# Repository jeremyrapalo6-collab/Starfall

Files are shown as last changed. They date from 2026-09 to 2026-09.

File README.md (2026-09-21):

# Starfall

Starfall is my first hardware project. I wanted to make a macropad because it seemed cool, and I chose to use my favorite colors, black and purple, along with my group name, **LTC**. This was a cool but long project, and I learned a lot while making it.

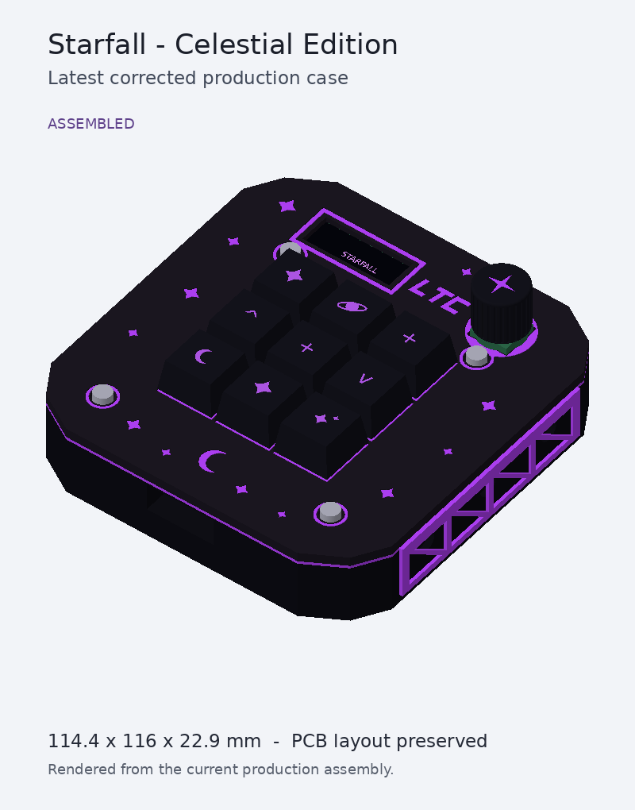
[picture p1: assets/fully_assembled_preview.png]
Starfall Celestial case


## What it is

Starfall is a 9-key macropad with a rotary encoder and a small OLED display. I designed it around a Seeed Studio XIAO RP2040 and made a custom PCB and case for it.

The macropad has three modes:

- **Everyday** - shortcuts for normal computer use
- **Gaming** - keys for games
- **Coding** - shortcuts for VS Code and Python

The bottom-right key changes between the three modes, and the OLED shows which mode is active.

## Design

The Celestial case pairs a black shell with purple side trusses, stars, a crescent and a bold slanted LTC logo. It has a stepped OLED surround and a recessed USB-C opening. Keycap symbols are illustrative; the preview includes the printable Starfall star knob.

## Hardware

- Seeed Studio XIAO RP2040
- 9 MX-compatible switches
- 9 1N4148 diodes
- 0.91-inch SSD1306 I2C OLED
- EC11 rotary encoder
- Custom 2-layer PCB
- Custom 3D-printed case
- 9 keycaps
- M3 screws and heat-set inserts

## Firmware

The firmware uses **KMK / CircuitPython**.

The three layers are:

### Everyday
Copy, paste, cut, undo, redo, select all, screenshot, media play/pause, and mode change.

### Gaming
A set of gaming keys plus the mode-change key.

### Coding
VS Code shortcuts such as run, debug, format, comment, terminal, split editor, command palette, quick open, and mode change.

## PCB

### Schematic

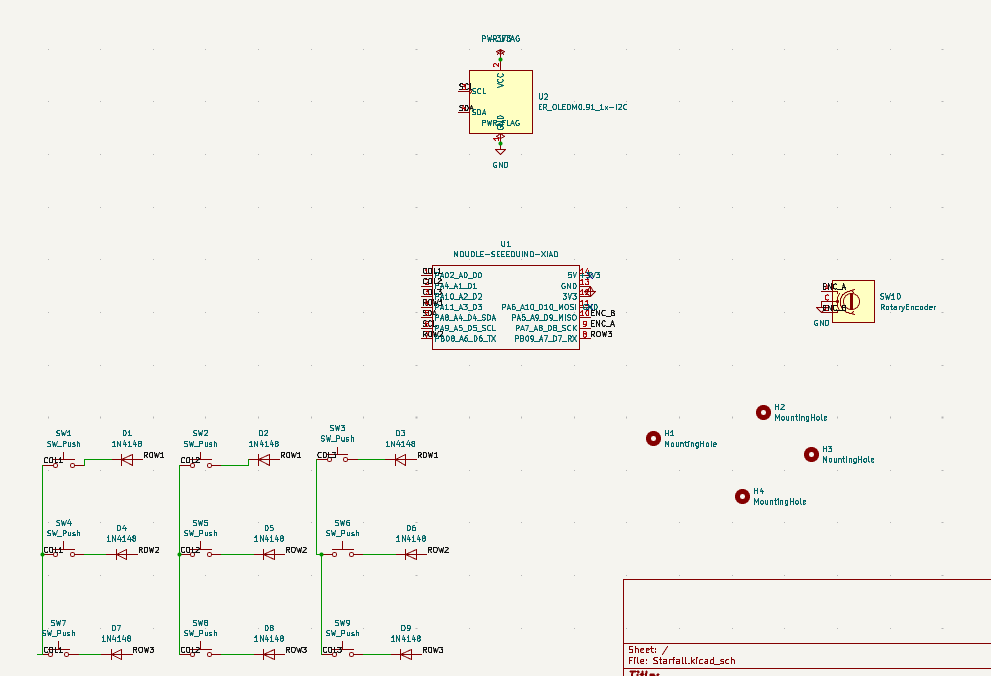
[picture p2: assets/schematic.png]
Starfall schematic


### PCB layout

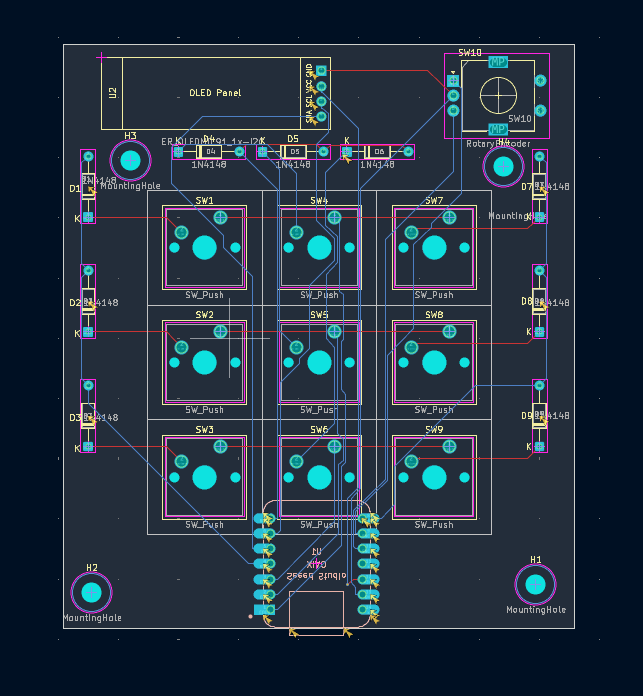
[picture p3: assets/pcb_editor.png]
Starfall PCB layout


### Front 3D view

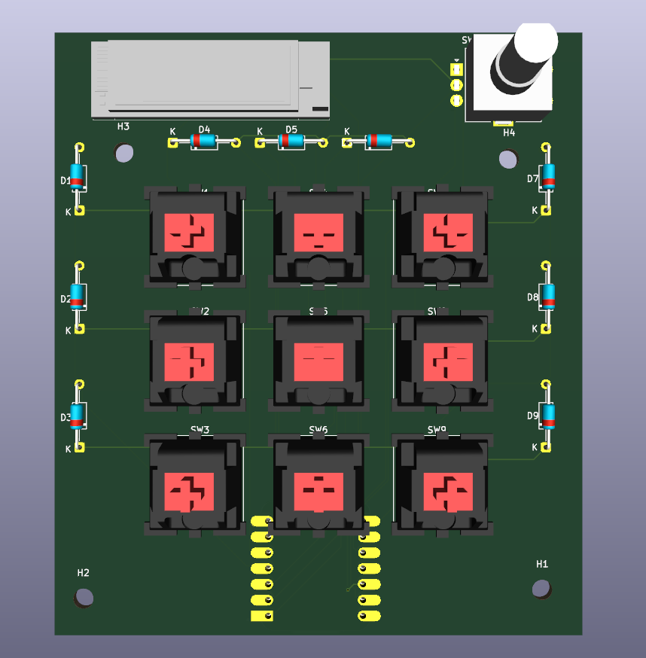
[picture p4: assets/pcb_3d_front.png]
Starfall PCB front


### Back 3D view

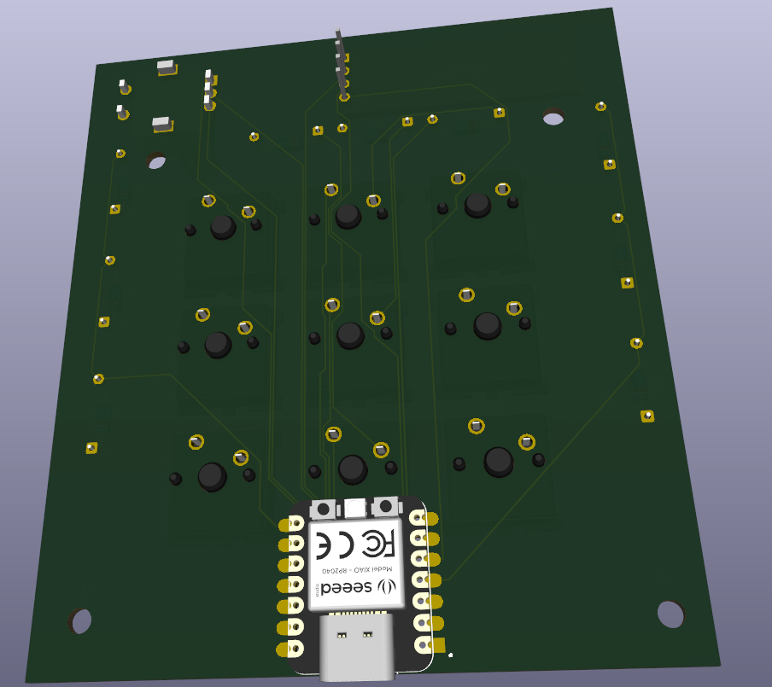
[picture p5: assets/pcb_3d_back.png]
Starfall PCB back


### Gerber check

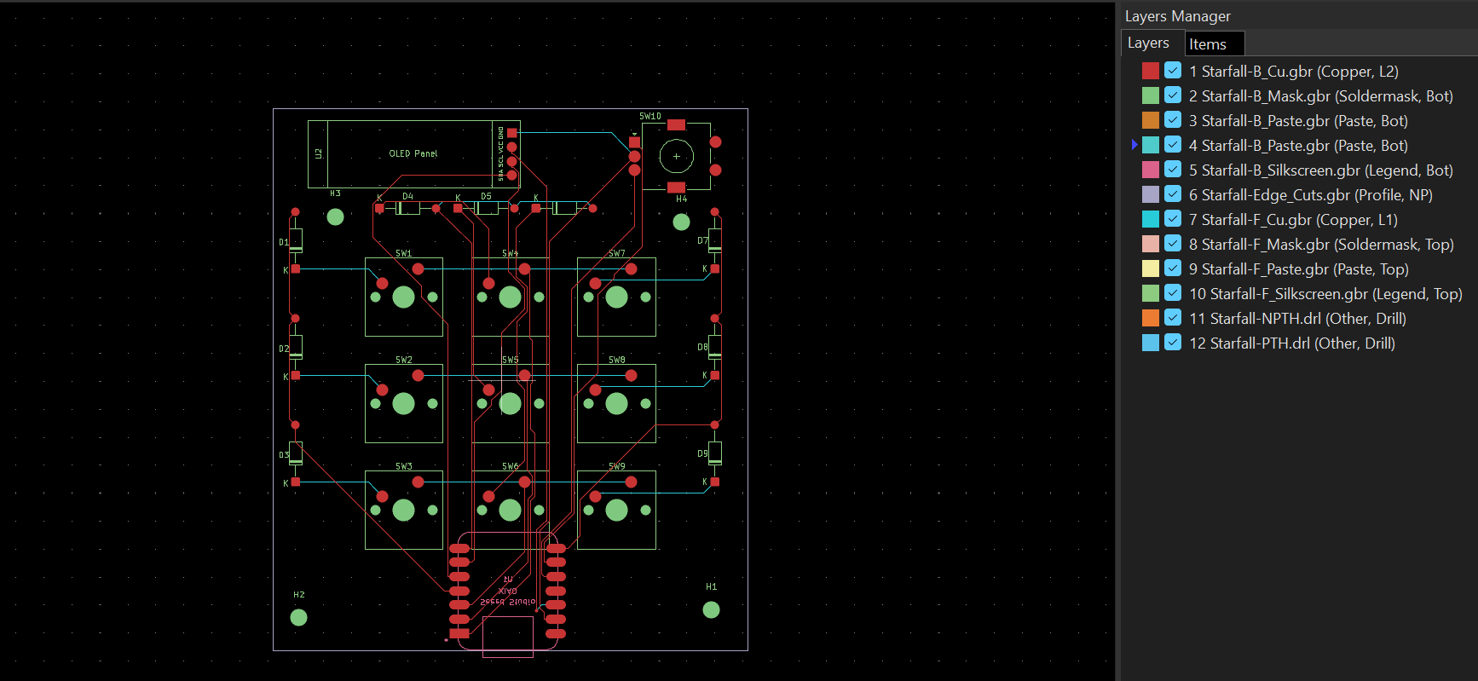
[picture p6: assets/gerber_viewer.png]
Starfall Gerber Viewer


## Case

The current case is **Starfall Celestial** (114.4 x 116 x 22.9 mm including side trusses).

- Black: `production/Top.STEP` and `production/Bottom.STEP`.
- Purple: `production/Middle_Purple.STEP` and `production/Purple_Inlays_Print_Layout.STEP` (one set of accents).
- Matching STL files are provided. `Purple_Inlays.STEP` is the same accents in assembled positions: do not print both accent files.
- [Fully assembled STEP](CAD/Starfall_Fully_Assembled.STEP) and [colored GLB](CAD/Starfall_Fully_Assembled_Colored.glb).
- [Design changes and physical fit checks](DESIGN_NOTES.md) and [assembly instructions](CAD/MECHANICAL_NOTES.md).

The L has been shifted 0.35 mm right. The taller bottom retains M3x16 screws with recessed insert seats. The PCB layout is unchanged. Print the switch/insert coupons and check your actual cable before a full case: CAD checks do not guarantee physical fit. All files in production are current. The case PNGs and older assembly filenames are synchronized to the latest Celestial case; PCB screenshots describe the unchanged PCB.

Automated CAD results: [mechanical](production/MECHANICAL_VALIDATION.json), [exports](production/EXPORT_VALIDATION.json), [structural intersections](production/STRUCTURAL_COLLISIONS.json).

### Current case views

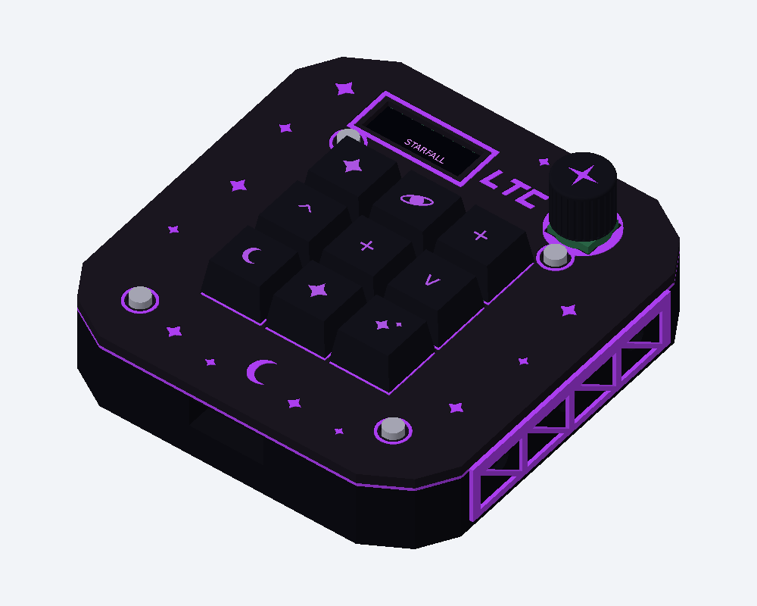
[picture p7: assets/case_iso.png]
Current assembled angled view


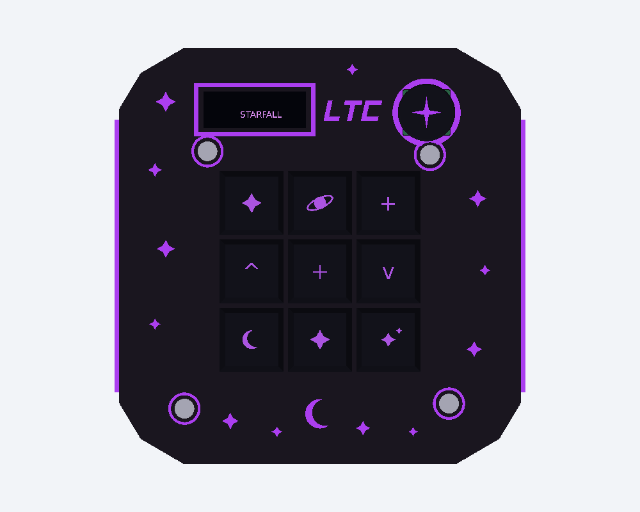
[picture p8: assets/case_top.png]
Current top view


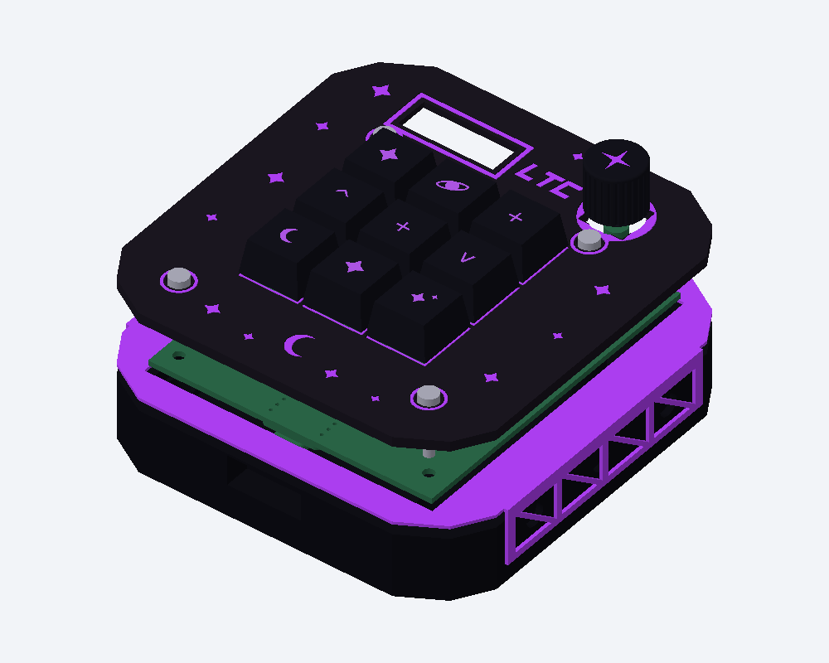
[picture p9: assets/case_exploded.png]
Current exploded assembly


These views are rendered from the current assembly. Keycaps and legends are illustrative accessories; the knob matches the printable files. See [asset descriptions](assets/SCREENSHOTS.md).

[Download the complete printer ZIP (case + knob + samples)](production/Starfall-Complete-Printer-Pack.zip).

### Printable Starfall encoder knob

[Download the knob print pack](production/knob/Starfall-Knob-Print-Pack.zip) or browse [individual STL/STEP files and instructions](production/knob/README.md).

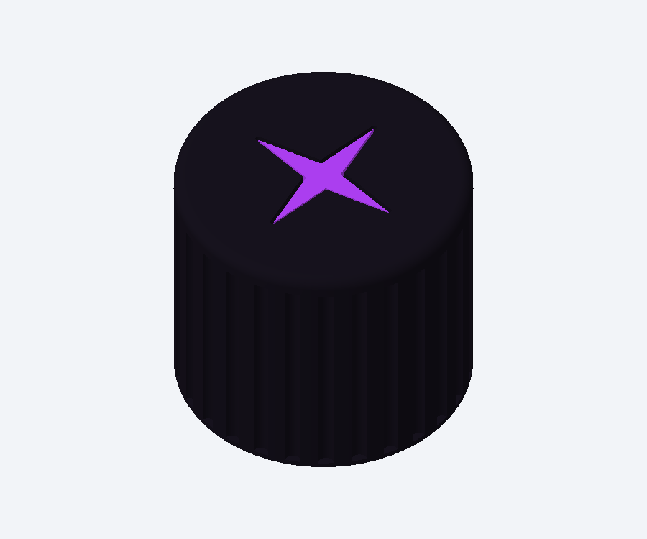
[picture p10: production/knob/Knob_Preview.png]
Black fluted knob with purple star


Print `Knob_Black.stl` in black and `Knob_Star_Purple.stl` in purple. Test `Dshaft_sample_6p2mm.stl` on the actual encoder first. The 6.1 and 6.3 mm samples provide fit alternatives; change the knob bore if needed before printing. Modeled clearances pass, but physical shaft fit and push travel require testing. Full-case previews and assembled STEP/GLB files now include this printable star knob.

## Bill of Materials

| Item | Qty | Part / Specification | Notes |
| --- | ---: | --- | --- |
| Microcontroller | 1 | Seeed Studio XIAO RP2040 | Hackpad MCU |
| Mechanical switch | 9 | MX-compatible PCB-mount switch | 1u switches |
| Diode | 9 | 1N4148 DO-35 through-hole | One per key |
| Rotary encoder | 1 | EC11E, 20 mm D-shaft | Encoder input |
| OLED | 1 | 0.91 in 128x32 SSD1306 I2C | 4-pin module |
| Keycap | 9 | 1u MX keycaps | 9 total |
| Encoder knob | 1 | D-shaft knob sized for EC11E | Knob for encoder |
| M3 screw | 4 | M3 x 16 mm | Deeper bottom; checked head envelope is diameter 5.5 x height 3 mm |
| Heat-set insert | 4 | M3 x 5 x 4 mm insert | 4.7 x 4.1 mm pocket below a 5.8 mm installation well |
| PCB | 1 | Starfall 2-layer PCB, 84.89 x 96.94 mm | Gerbers in `production/` |
| Case: black | 1 set | `Top.STEP` + `Bottom.STEP` | 3D printed |
| Case: purple | 1 set | `Middle_Purple.STEP` + `Purple_Inlays.STEP` | 3D printed accents |

The full BOM with source/reference links is also available in [`BOM.csv`](BOM.csv).

## Files

- `PCB/` - KiCad schematic, PCB, and project files
- `CAD/` - case, assemblies, and full-color GLB preview
- `production/` - final STEP/STL case parts, Gerbers, print-ready check, and `main.py`
- `Firmware/` - KMK firmware source
- `assets/` - project screenshots and graphics
- `tools/` - reproducible final-case generator
- `BOM.csv` - bill of materials with reference links

## What I learned

This was my first project, so I learned a lot about KiCad, schematics, PCB routing, key matrices, diodes, 3D models, case design, Gerbers, and firmware. It took a while, but seeing the whole project come together was worth it.

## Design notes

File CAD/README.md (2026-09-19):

# Current case downloads

- Starfall_Fully_Assembled.STEP: full Celestial assembly.
- Starfall_Fully_Assembled_Colored.glb: full colored assembly.
- Starfall_Reactor_Celestial_FINAL_COLORED_CASE.STEP: case-only assembly.
- Starfall_Mechanical_Assembly.STEP: case with electronics used for fit checks.

Starfall_assembled.STEP and Starfall_case_assembly.STEP now mirror the current full and case-only assemblies. All GLB filenames in CAD/ and assets/ mirror the current full colored assembly. These compatibility names are refreshed by tools/make_full_assembly.py.

Use ../production/ for individual printable parts. build_case.py is the historical generator; the current generator is ../tools/generate_final_case.py. Original electronics STEP files remain source references.

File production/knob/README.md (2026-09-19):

# Starfall star knob

Print Knob_Black.stl in black and Knob_Star_Purple.stl in purple. The purple star is flat on the bed; glue into the top recess sparingly. It sits 0.10 mm below the knob top. Do not print Knob_Assembled.STEP as an extra part.

Print the 6.2 mm Dshaft sample first. It is the SAME bore as the knob. The 6.1 and 6.3 mm samples offer tighter/looser comparisons. Samples are labelled by filename; keep them separate. If 6.2 does not grip comfortably, adjust the knob bore using the selected sample before printing. Do not force a tight fit or glue the knob to the encoder. This is a friction-fit design; real shaft/printer tolerances must be tested.

Knob: 16 mm diameter, 14.2 mm high, 28 grip flutes, 6.2 mm D bore with flat at +2.5 mm, 12.4 mm deep; 9 mm collar relief 3.8 mm deep. Print the black body with its closed star face on the bed and its bore facing upward; inspect/clean any bridging at the bore transition. Ask the printer to preserve the small top pocket and account for first-layer expansion. No extra screw or insert is needed.

The full rotation envelope clears the modeled case/electronics/screw heads, including 1.1 mm downward travel allowance. Actual push travel and shaft retention remain physical checks. The original EC11 model is the dimensional reference, not a measurement of the delivered part.

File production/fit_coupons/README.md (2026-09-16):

# Fit samples before the full case

These are new mechanical test pieces, not parts of the finished enclosure. Print them using the same material, nozzle and settings planned for the case.

## Switch sample

`Switch_retention_14p2_14p4_14p6.STEP` has three openings. One, two and three marks identify 14.2, 14.4 and 14.6 mm lower openings respectively. All have the upper relief and 1.3 mm nominal retaining-lip stack. The case currently uses the 14.2 mm opening with an upper-edge relief.

Fit an actual supplied switch. Check that it inserts without excessive force, both latches engage, it cannot easily pull out, and a keycap can move through its full stroke. Choose the smallest opening that works reliably. If the 14.2 mm option fails, adjust the case before printing it; this sample does not automatically change the case files.

## Insert-access sample

`Insert_well_4p6_4p7_4p8.STEP` reproduces the tall posts and deep installation wells. From left to right in the source coordinates, the heat-set pockets are 4.6, 4.7 and 4.8 mm in diameter. The case uses 4.7 mm. Each post has a 5.8 mm access well and a 4.1 mm deep insert pocket.

Before heating, confirm the soldering iron's insert-setting tip fits down the access well. Install the actual M3 x 5 x 4 mm insert so its top is **6.9 mm below the post's upper support surface**. Do not leave the insert flush with the top of the post: the deep seat is necessary for the M3 x 16 screw stack. Inspect for splitting, melting through, loose inserts and thread obstruction. Let it cool and test the screw gently.

The well is deliberately tested here because the exact supplied iron tip and insert knurl dimensions are not available as measured parts. If the tip cannot reach or the insert cannot be set accurately, revise the mounting arrangement rather than forcing it.

Do not overtighten screws to compensate for a dimensional mismatch.

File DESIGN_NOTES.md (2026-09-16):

# Starfall polished revision

## Changes in this revision
- Stepped OLED window: 31.2 x 12.2 mm underside clearance, 28.4 x 10.2 mm viewing window above Z=4.2. The modeled display/glass reaches Z=3.765, leaving 0.435 mm below the ledge. The modeled active area stays fully within the window. The complete assembly now shows the actual OLED glass in black rather than a floating, undersized decorative screen.
- USB: recessed outer face at Y=-50.3, only 1.06 mm ahead of the existing connector shell. Outer cable recess 22 x 9 mm; socket aperture 10.2 x 5.4 mm. PCB and connector are not moved. Actual cable overmold fit must be checked.
- Custom bold slanted LTC inlay (L shifted 0.35 mm right); twelve purple stars and a crescent across unused top areas.
- Existing M3x16 stack, insert seats and PCB layout retained. Overall case 114.4 x 116 x 22.9 mm including side trusses.

Use only this package's production files and full assembly for this revision. Top and Bottom are black; Middle_Purple and Purple_Inlays are purple. The middle band includes the side trusses; print its flat upper face on the bed. Print loose accents using Purple_Inlays_Print_Layout.

## Physical checks before a full print
Switch clearance is about 0.030 mm in the model: use the supplied fit coupon and actual switches first. Test the deep insert coupon with the real iron and insert (insert top 6.9 mm below support top). Verify cable overmold, keycap travel and actual knob skirt/head dimensions. Passing CAD checks cannot guarantee physical fit. Keycap symbols and knob in full assemblies are illustrative accessories, not validated printable replacement parts.

See production/MECHANICAL_VALIDATION.json, EXPORT_VALIDATION.json and STRUCTURAL_COLLISIONS.json for results. CAD/MECHANICAL_NOTES.md describes the retained screw/insert assembly; the OLED and USB dimensions above supersede its previous openings.

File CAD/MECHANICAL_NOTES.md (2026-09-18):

# Reactor Celestial mechanical correction

This revision keeps the PCB layout, Reactor silhouette and celestial artwork. The user selected a taller bottom to retain the supplied M3 x 16 screws.

## Corrected construction

- Overall enclosure: **114.4 x 116 x 22.9 mm**, excluding keycaps/knob. Bottom Z=-17.00, top Z=5.90. This is 6.4 mm taller than the prior Reactor case.
- PCB underside: Z=-0.70; reference thickness: **1.60 mm**. PCB outline remains 84.89 x 96.94 mm, with 0.40 mm nominal side clearance. PCB and Gerber files are unchanged.
- Floor top: Z=-14.90, giving a 2.10 mm floor. Four 8.20 mm posts extend into that floor and form one solid with the shell. Their upper support surfaces are at Z=-0.70.
- Upper retaining collars end at Z=1.15, leaving 0.25 mm above the nominal PCB top. They limit movement without forcing the board into an exact zero-clearance sandwich.
- Each post has a **5.80 mm installation well** down to Z=-7.60, an open **4.70 mm diameter x 4.10 mm deep insert pocket**, and a **3.40 mm tip-relief bore to Z=-12.10**.
- Install a 4 mm long insert with its **top at Z=-7.60**, i.e. **6.90 mm below the post top**. The insert must not sit flush with the post top. Install it before the PCB blocks access.
- Screw seats are **6.40 mm diameter x 1.25 mm deep** (seat Z=4.65). A 16 mm under-head screw ends at Z=-11.35, giving **3.75 mm nominal thread engagement** and **0.75 mm tip-relief clearance**. The tested head envelope is 5.50 mm diameter x 3.00 mm high; heads stand proud of the plate.
- The encoder opening combines the circular shaft opening with rounded rectangular corner relief for the actual 12 x 11.6 mm body. Its decorated ring is trimmed to clear it.
- Switch openings keep a 14.20 mm lower aperture and 16.40 mm upper aperture. The top of the retaining lip is relieved from Z=3.85 to 4.20 to clear the modeled switch transition. Square accent frames replace circular rings that overlapped switch housings.
- Diode, OLED header and OLED flex/contact reliefs follow the updated 1.60 mm board reference, with a target 0.40 mm clearance where the remaining roof permits it.
- USB socket aperture: **10.2 x 5.4 mm** within a **22 x 9 mm** outer recess. The recessed face is 1.06 mm ahead of the fixed connector shell. Test the actual cable overmold.
- OLED window: **28.4 x 10.2 mm**, above the **31.2 x 12.2 mm** underside glass clearance. The ledge clears the modeled glass/display by 0.435 mm.
- Decorative pockets are generated from the actual insert contours with 0.18 mm XY expansion. Overlapping decorative solids are fused and details inside switch openings are removed.

## Assembly and physical checks

1. Print and test `production/fit_coupons/` with the actual switches, inserts and printer settings. The insert sample reproduces the deep access well: confirm the soldering tip reaches the pocket before printing the whole case.
2. Heat-set the four inserts in the bottom to the specified depth, let them cool and check the threads. Keep melted plastic out of the screw-tip relief.
3. Dry-fit the PCB, USB cable and electronics. Match the reference placement; extra header sockets or spacers change the fit. Shorten OLED leads as represented in the reference and keep other leads/solder within the available cavity.
4. Check switch latches, keycap travel, encoder knob skirt and actual screw heads. Fit and tighten the screw near the encoder before installing the knob. Do not use screw force to bend the PCB or pull interfering parts together.
5. Fit accents using an agreed print process. `Purple_Inlays_Print_Layout` contains separate flat pieces for single-colour printing; `Purple_Inlays` preserves assembled positions. Several accents are thin and require appropriate nozzle/layer settings or a multi-material workflow. Adhesive attachment is required for separately printed accents.

The small fit samples are needed for a reliable physical-fit decision because no delivered hardware or printed parts were available for measurement. A successful CAD collision test does not prove switch latch retention or heat-set performance.

## Which files to use

Current generator: `tools/generate_final_case.py` plus `tools/mechanical_fit.py`. The workflow pins CAD kernel versions and refuses to commit generated output when a tested collision or invalid structural solid is found.

Current production parts: `production/Top.STEP`, `Bottom.STEP`, `Middle_Purple.STEP`, and `Purple_Inlays.STEP` (or the separate accent layout). Matching STL files are provided. Current fit assembly: `CAD/Starfall_Mechanical_Assembly.STEP`. The reference PCB is corrected to 1.60 mm in `CAD/Starfall_fit_reference_1p6mm.STEP`; the original source electronics model is retained unchanged.

`CAD/build_case.py`, `CAD/Starfall_assembled.STEP`, `CAD/Starfall_case_assembly.STEP` and older case screenshots are historical. They are not the corrected production geometry. The coloured GLB includes presentation keycaps/knob, not measured hardware.

Measured results are in `production/MECHANICAL_VALIDATION.json` and included in `CASE_PRINT_READY_CHECK.json`. Their status explicitly retains the physical-fit qualification above.

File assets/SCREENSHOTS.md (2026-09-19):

# Asset guide

Current Celestial case views, generated from CAD/Starfall_Fully_Assembled_Colored.glb:

- fully_assembled_preview.png: assembled presentation with dimensions.
- case_iso.png: angled assembled view.
- case_top.png: top view.
- case_exploded.png: exploded assembly (parts separated for illustration).
- Starfall_render_colored.glb: synchronized copy of the current colored assembly.

PCB, schematic and Gerber screenshots describe the unchanged electronics. keycap_icon_*.png, oled_screen_graphic.png and front_starfall_wordmark.png are concept artwork, not evidence of printed keycaps, screen firmware, or an engraved front wordmark. The assembled preview uses illustrative keycaps and knob; print only production case parts.

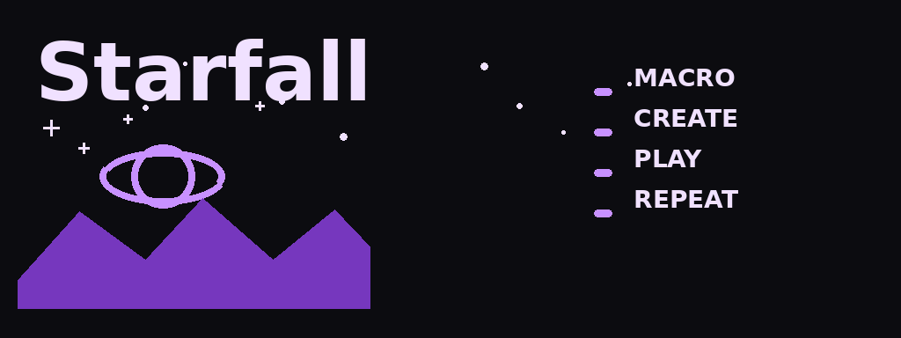
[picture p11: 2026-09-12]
assets/oled_screen_graphic.png

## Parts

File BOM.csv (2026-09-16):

Item | Qty | Part / Specification | Reference / Source link | Notes
Microcontroller | 1 | Seeed Studio XIAO RP2040 | https://www.seeedstudio.com/XIAO-RP2040-v1-0-p-5026.html | Required Hackpad MCU
Mechanical switch | 9 | MX-compatible PCB-mount switch | https://www.cherry.de/en-us/product/mx2a | 1u switches
Diode | 9 | 1N4148 DO-35 through-hole | https://assets.onsemi.com/pdf/datasheet/1n914-d.pdf | One per key matrix position
Rotary encoder | 1 | EC11E, 20 mm D-shaft | https://hackpad.hackclub.com/add-components | Hackpad approved encoder type
OLED | 1 | 0.91 in 128x32 SSD1306 I2C | https://hackpad.hackclub.com/add-components | 4-pin GND/VCC/SCL/SDA module
Keycap | 9 | 1u MX keycaps | https://hackpad.hackclub.com/resources | 9 total
Encoder knob | 1 | D-shaft knob sized for EC11E | https://hackpad.hackclub.com/add-components | Visual assembly includes a placeholder knob
M3 screw | 4 | M3 x 16 mm | https://hackpad.hackclub.com/resources | Deeper bottom; checked head envelope diameter 5.5 mm and height 3 mm
Heat-set insert | 4 | M3 x 5 x 4 mm insert | https://stardance.hackclub.com/missions/hackpad/guide | 4.7 x 4.1 mm pocket; insert top 6.9 mm below support top via 5.8 mm access well
PCB | 1 | Starfall 2-layer PCB, 84.89 x 96.94 mm | https://hackpad.hackclub.com/submitting | Gerbers required in production/
Case: black | 1 set | Top.STEP + Bottom.STEP | https://hackpad.hackclub.com/submitting | 3D printed
Case: purple | 1 set | Middle_Purple.STEP + Purple_Inlays.STEP | https://hackpad.hackclub.com/submitting | 3D printed accent parts

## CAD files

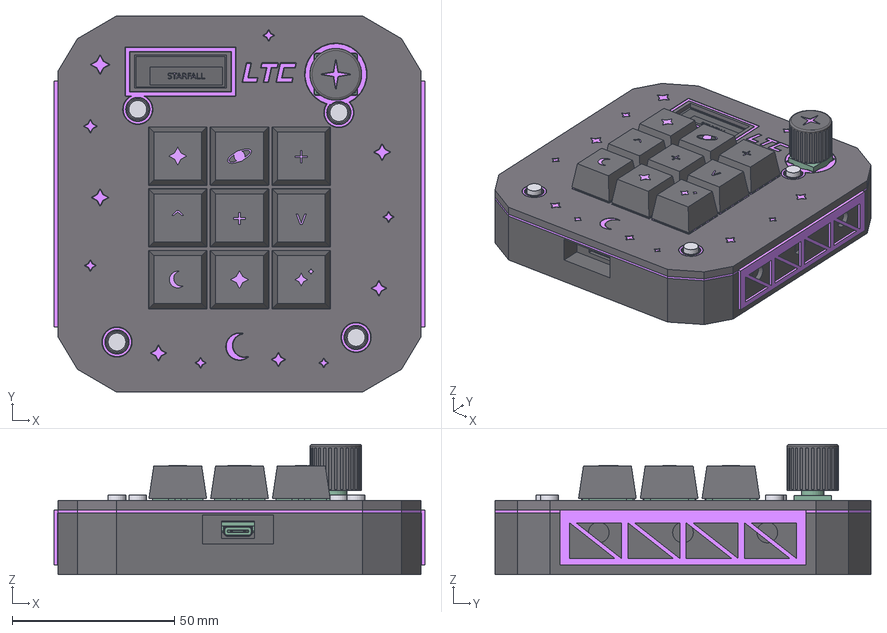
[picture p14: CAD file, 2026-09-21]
CAD/Starfall_assembled.STEP
114.4 x 116.0 x 40.2 mm
Bottom
Middle_Purple
Top
Purple_Inlays
Electronics
Actual_OLED_Glass
Encoder_Knob_Star
Keycaps
Encoder_Knob
M3_Screws
OLED_STARFALL
Illustrative_Keycap_Legends

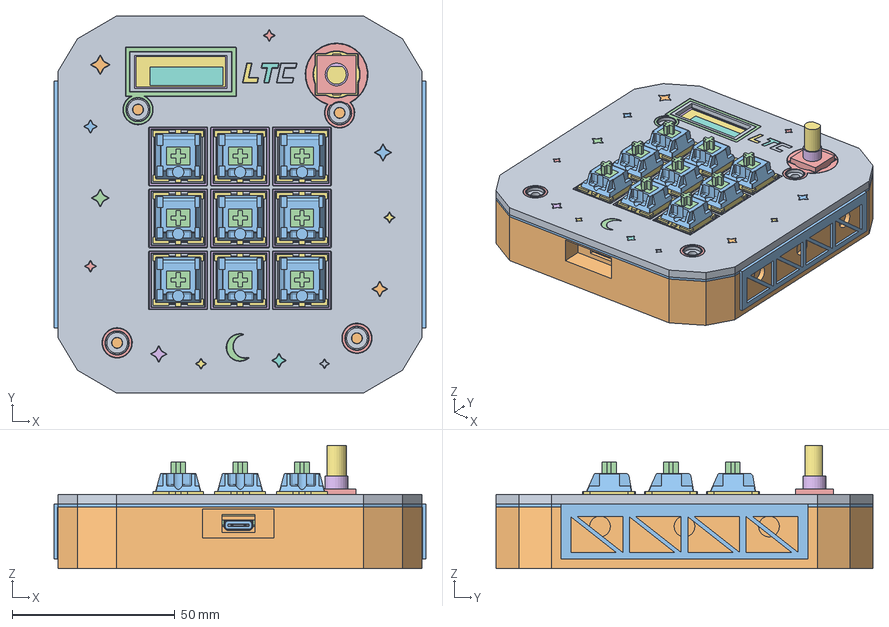
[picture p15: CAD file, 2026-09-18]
CAD/Starfall_Mechanical_Assembly.STEP
114.4 x 116.0 x 38.0 mm
Top
Bottom
Middle_Purple
Purple inlays
Actual electronics with 1.6mm PCB

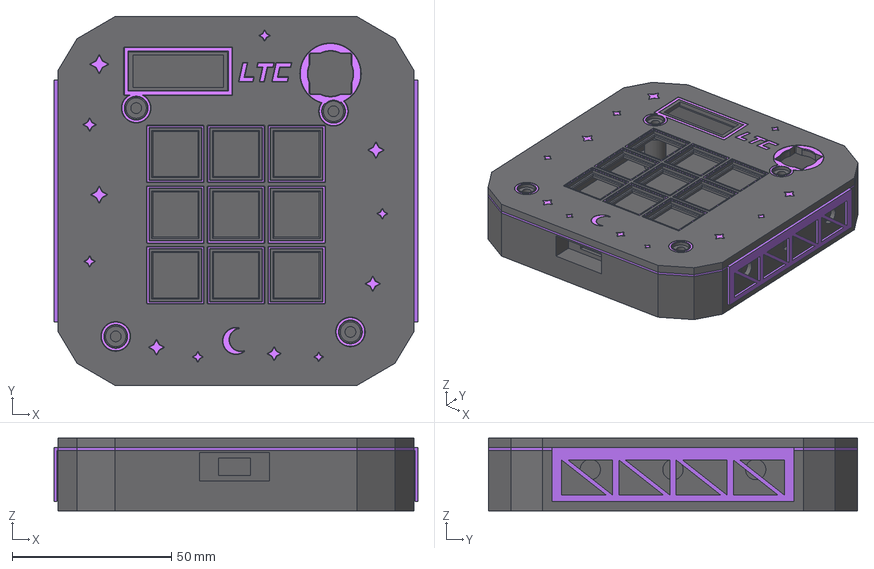
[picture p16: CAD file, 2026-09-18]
CAD/Starfall_case_assembly.STEP
114.4 x 116.0 x 22.9 mm
Bottom black
Middle purple
Top black
Purple celestial inlays

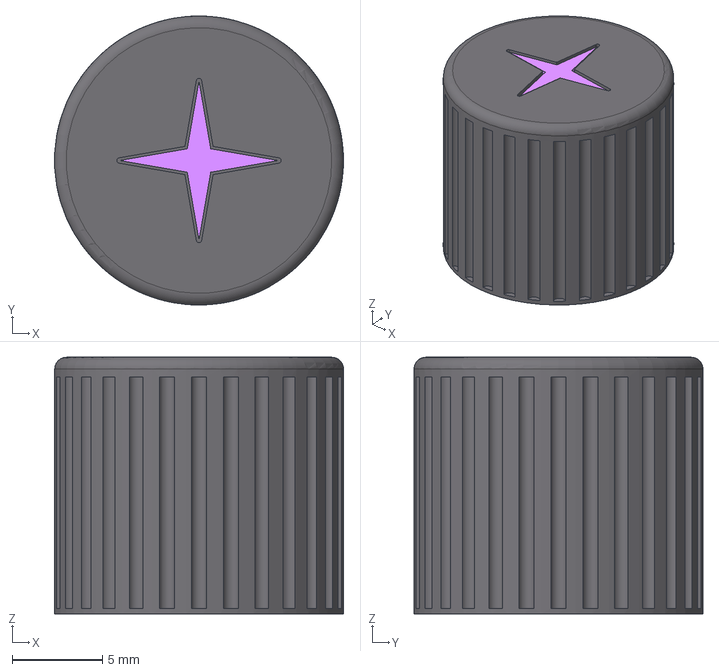
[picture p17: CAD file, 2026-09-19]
production/knob/Knob_Assembled.STEP
16.0 x 16.0 x 14.2 mm
Black_fluted_knob
Purple_star

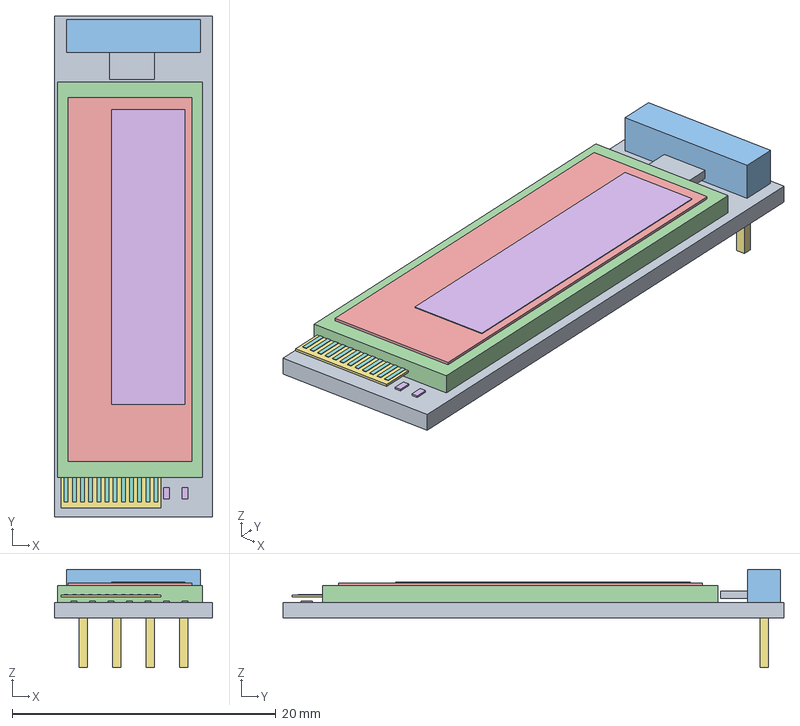
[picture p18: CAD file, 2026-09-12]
CAD/ER_OLEDM0.91_1x-I2C_FULL_SHORT_PINS.step
12.0 x 38.0 x 7.44 mm

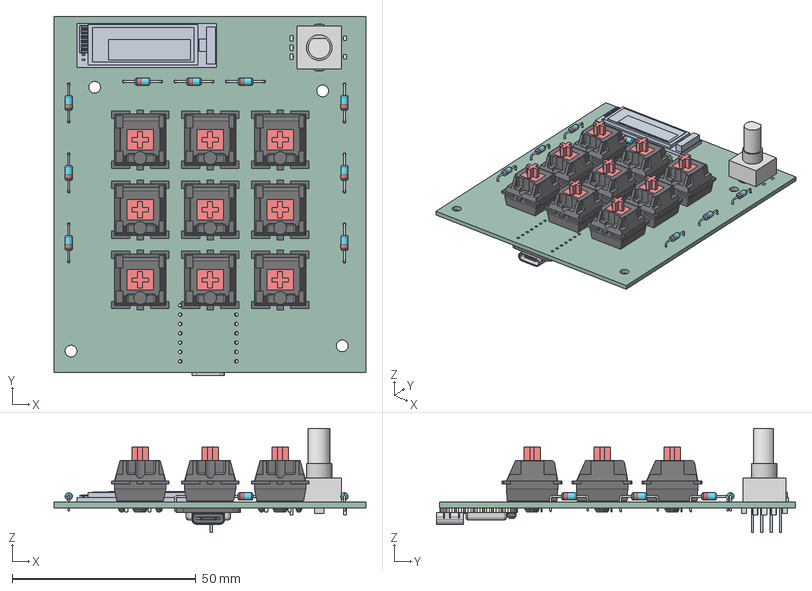
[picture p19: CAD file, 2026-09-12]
PCB/Starfall_board_export.step
84.9 x 97.7 x 28.3 mm
D_DO-35_SOD27_P10.16mm_Horizontal x 9
EC11E_body
EC11E_bushing
EC11E_shaft
pin_A
pin_C
pin_B
S1
S2
MP_1
MP_2
type-c v2
smd_button v3
DOUT
DIN
VSS
VDD
smd_button v3(Mirror)
Starfall_PCB

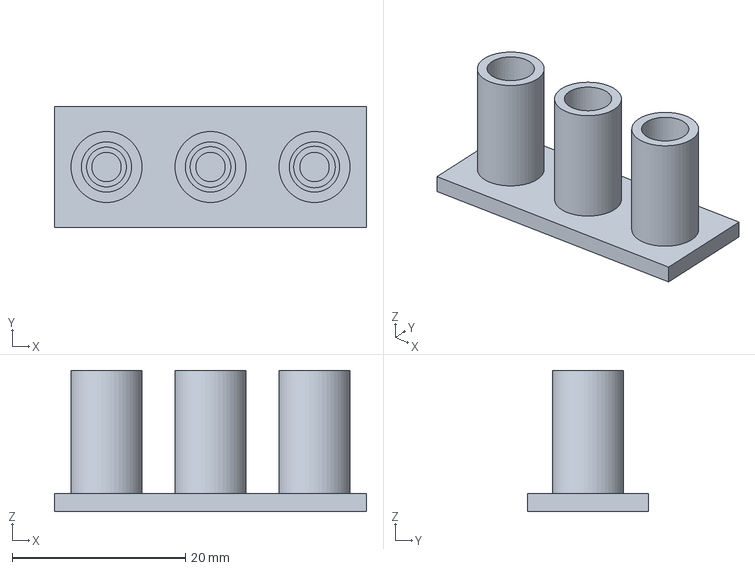
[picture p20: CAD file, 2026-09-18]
production/fit_coupons/Insert_well_4p6_4p7_4p8.STEP
36.0 x 14.0 x 16.3 mm

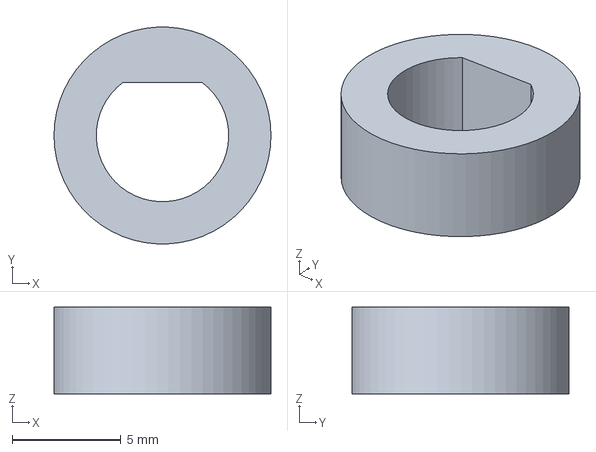
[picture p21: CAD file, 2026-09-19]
production/knob/Dshaft_sample_6p1mm.STEP
10.0 x 9.99 x 4.00 mm

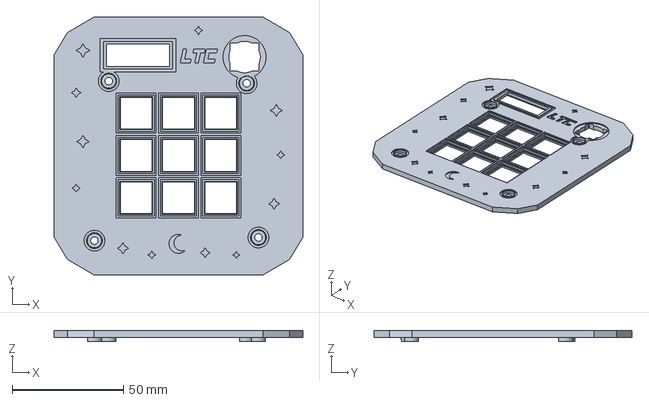
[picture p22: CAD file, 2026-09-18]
production/Top.STEP
112.0 x 116.0 x 4.75 mm

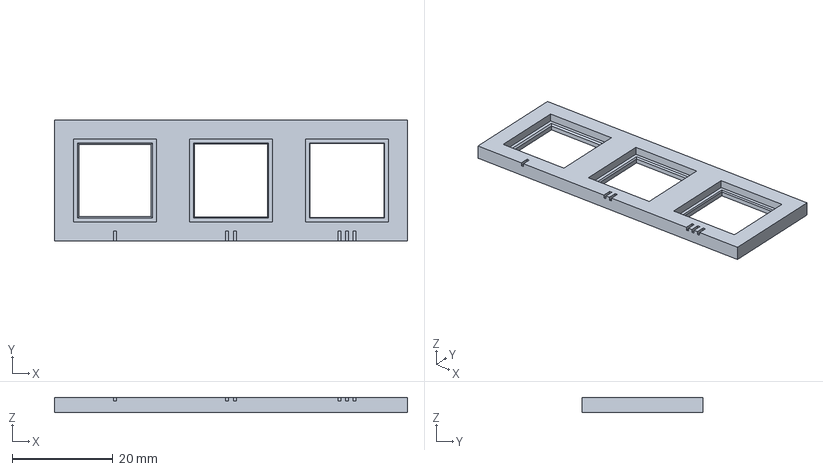
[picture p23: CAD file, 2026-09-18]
production/fit_coupons/Switch_retention_14p2_14p4_14p6.STEP
70.0 x 24.0 x 3.00 mm

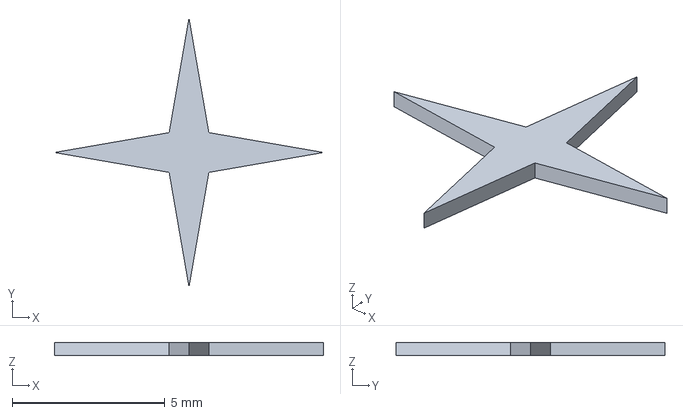
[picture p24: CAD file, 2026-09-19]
production/knob/Knob_Star_Purple.STEP
8.80 x 8.80 x 0.44 mm

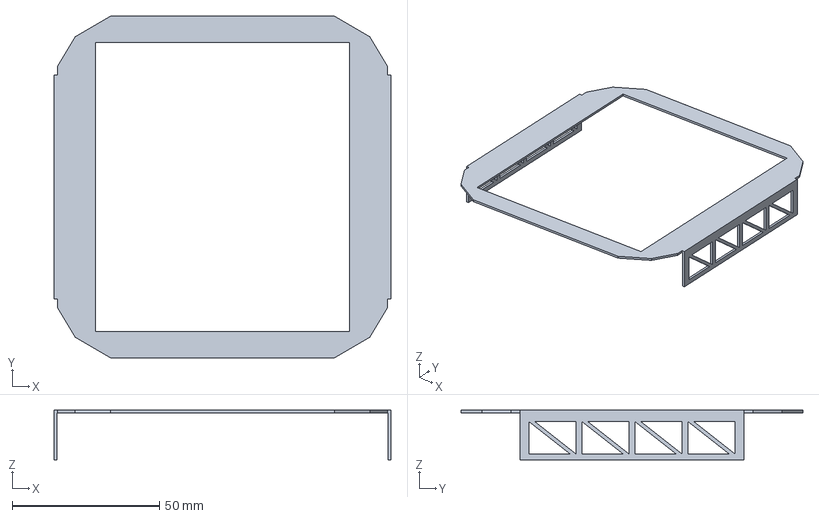
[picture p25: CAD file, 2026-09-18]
production/Middle_Purple.STEP
114.4 x 116.0 x 16.9 mm

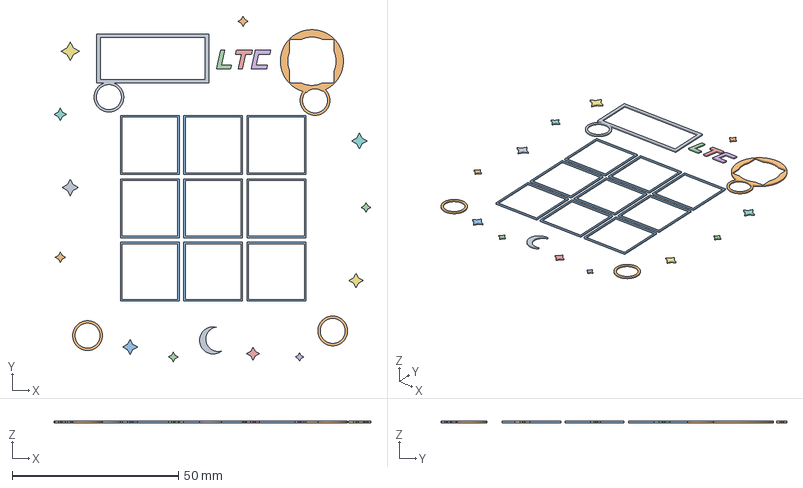
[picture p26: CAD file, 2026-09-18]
production/Purple_Inlays.STEP
95.4 x 104.1 x 0.48 mm

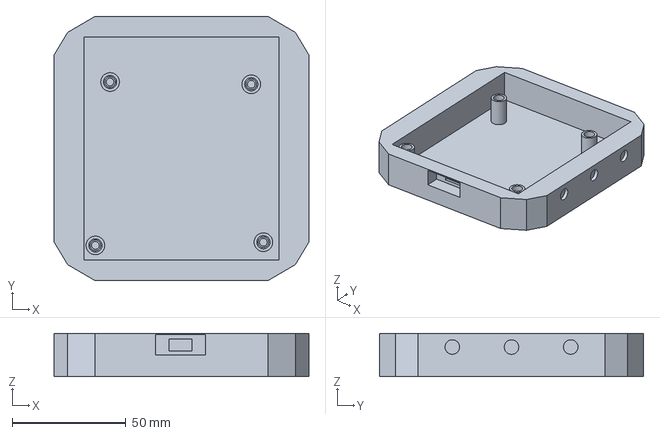
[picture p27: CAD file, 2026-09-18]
production/Bottom.STEP
112.0 x 116.0 x 19.0 mm

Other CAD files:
production/knob/Dshaft_sample_6p3mm.STEP
production/knob/Knob_Black.STEP
CAD/Starfall_electronics_short_OLED.step
CAD/Starfall_fit_reference_1p6mm.STEP
production/Bottom.stl
production/Middle_Purple.stl
production/Purple_Inlays.stl
production/Purple_Inlays_Print_Layout.STEP
production/Purple_Inlays_Print_Layout.stl
production/Top.stl
production/fit_coupons/Insert_well_4p6_4p7_4p8.stl
production/fit_coupons/Switch_retention_14p2_14p4_14p6.stl
production/knob/Dshaft_sample_6p1mm.stl
production/knob/Dshaft_sample_6p2mm.STEP
production/knob/Dshaft_sample_6p2mm.stl
production/knob/Dshaft_sample_6p3mm.stl
production/knob/Knob_Black.stl
production/knob/Knob_Star_Purple.stl

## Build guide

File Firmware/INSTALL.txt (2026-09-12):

STARFALL FIRMWARE SETUP

1. Flash CircuitPython onto the Seeed Studio XIAO RP2040.
2. Copy current KMK firmware's kmk/ directory onto CIRCUITPY.
3. Copy adafruit_ssd1306.mpy, adafruit_framebuf.mpy, and adafruit_bus_device/ into CIRCUITPY/lib/.
4. Copy main.py to the root of CIRCUITPY.
5. If encoder direction is backwards, swap D8 and D9 in encoder.pins.
6. OLED address is set to 0x3C.

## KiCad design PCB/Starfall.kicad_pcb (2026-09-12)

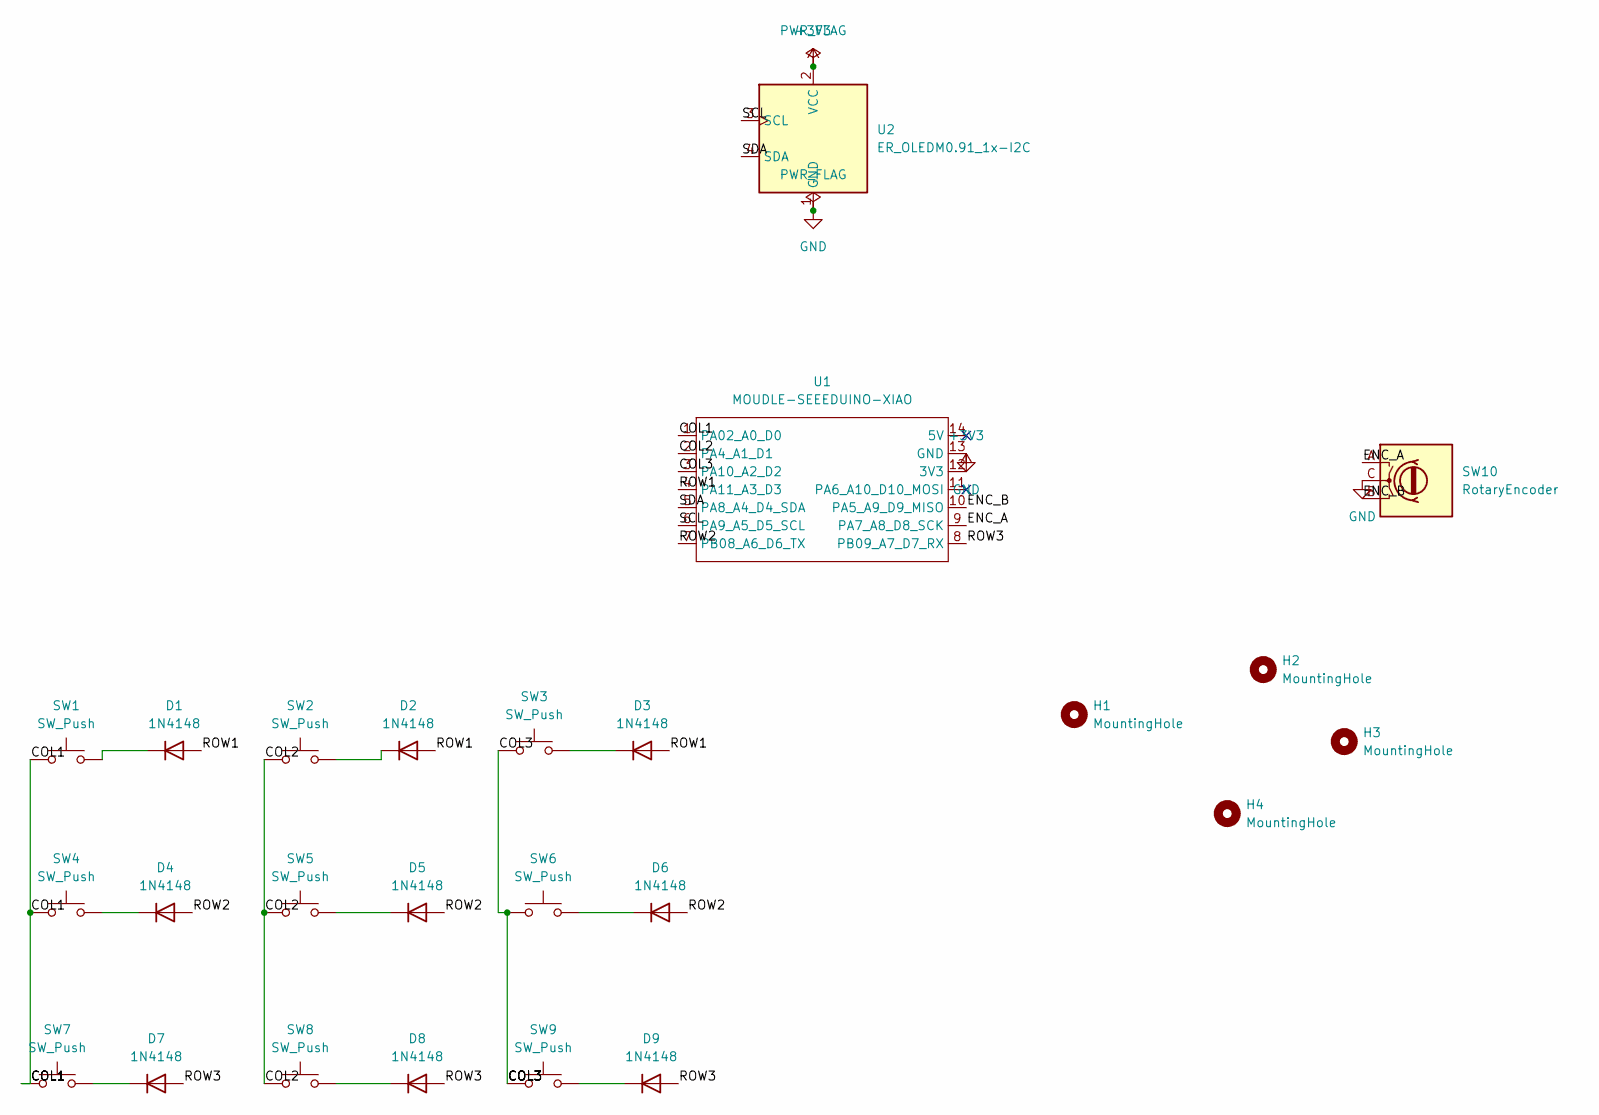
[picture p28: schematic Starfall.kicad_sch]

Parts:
D1, D2, D3, D4, D5, D6, D7, D8, D9: 1N4148; D_DO-35_SOD27_P10.16mm_Horizontal
H1, H2, H3, H4: MountingHole; MountingHole_3.2mm_M3
SW1, SW2, SW3, SW4, SW5, SW6, SW7, SW8, SW9: SW_Push; SW_Cherry_MX_1.00u_PCB
SW10: RotaryEncoder; RotaryEncoder_Alps_EC11E-Switch_Vertical_H20mm
U1: MOUDLE-SEEEDUINO-XIAO; XIAO-Generic-Hybrid-14P-2.54-21X17.8MM
U2: ER_OLEDM0.91_1x-I2C; SSD1306-0.91-OLED-4pin-128x32

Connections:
+3V3: U1.12 (3V3), U2.2 (VCC)
/COL1: SW1.1, SW4.1, SW7.1, U1.1 (PA02_A0_D0)
/COL2: SW2.1, SW5.1, SW8.1, U1.2 (PA4_A1_D1)
/COL3: SW3.1, SW6.1, SW9.1, U1.3 (PA10_A2_D2)
/ENC_A: SW10.A, U1.9 (PA7_A8_D8_SCK)
/ENC_B: SW10.B, U1.10 (PA5_A9_D9_MISO)
/ROW1: D1.2 (A), D2.2 (A), D3.2 (A), U1.4 (PA11_A3_D3)
/ROW2: D4.2 (A), D5.2 (A), D6.2 (A), U1.7 (PB08_A6_D6_TX)
/ROW3: D7.2 (A), D8.2 (A), D9.2 (A), U1.8 (PB09_A7_D7_RX)
/SCL: U1.6 (PA9_A5_D5_SCL), U2.3 (SCL)
/SDA: U1.5 (PA8_A4_D4_SDA), U2.4 (SDA)
GND: SW10.C, U1.13 (GND), U2.1 (GND)
unnamed: D1.1 (K), SW1.2
unnamed: D2.1 (K), SW2.2
unnamed: D3.1 (K), SW3.2
unnamed: D4.1 (K), SW4.2
unnamed: D5.1 (K), SW5.2
unnamed: D6.1 (K), SW6.2
unnamed: D7.1 (K), SW7.2
unnamed: D8.1 (K), SW8.2
unnamed: D9.1 (K), SW9.2

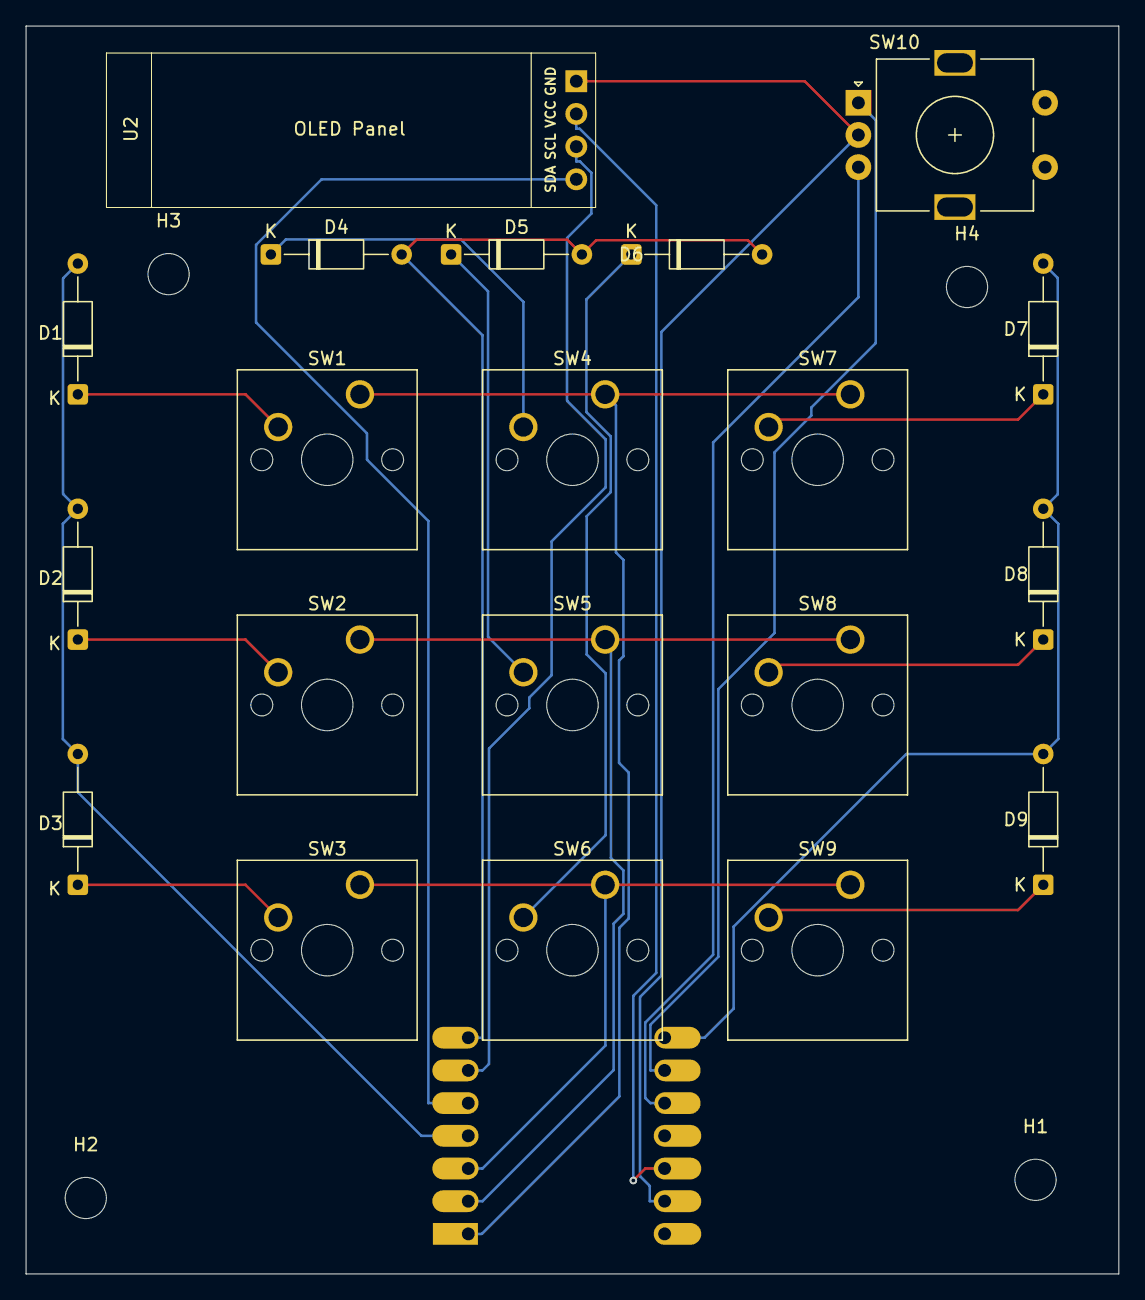
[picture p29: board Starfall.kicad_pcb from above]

Board: 2 copper layers, 84.9 x 96.9 mm, 25 parts (1 on the bottom side), 21 nets.

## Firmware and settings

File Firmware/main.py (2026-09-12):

# Starfall Hackpad - KMK / CircuitPython
# XIAO RP2040 | 9-key matrix | EC11 encoder | 0.91in SSD1306 OLED

import board
import busio

from kmk.kmk_keyboard import KMKKeyboard
from kmk.keys import KC
from kmk.scanners import DiodeOrientation
from kmk.modules.layers import Layers
from kmk.modules.encoder import EncoderHandler
from kmk.extensions.media_keys import MediaKeys
from kmk.extensions import Extension

keyboard = KMKKeyboard()
layers = Layers()
encoder = EncoderHandler()
keyboard.modules = [layers, encoder]
keyboard.extensions.append(MediaKeys())

# PCB pinout
keyboard.col_pins = (board.D0, board.D1, board.D2)
keyboard.row_pins = (board.D3, board.D6, board.D7)
keyboard.diode_orientation = DiodeOrientation.ROW2COL

# EC11 rotation. The switch/push function is not wired as a separate input.
encoder.pins = ((board.D8, board.D9, None, False),)

# Persistent mode keys. The bottom-right key cycles modes because each layer
# maps that same physical key to the next default layer.
TO_EVERYDAY = KC.DF(0)
TO_GAMING = KC.DF(1)
TO_CODING = KC.DF(2)

# Common shortcuts
COPY = KC.LCTL(KC.C)
PASTE = KC.LCTL(KC.V)
CUT = KC.LCTL(KC.X)
UNDO = KC.LCTL(KC.Z)
REDO = KC.LCTL(KC.Y)
SELECT_ALL = KC.LCTL(KC.A)
SCREENSHOT = KC.LGUI(KC.LSFT(KC.S))

# VS Code / Python shortcuts
RUN_NO_DEBUG = KC.LCTL(KC.F5)
DEBUG = KC.F5
FORMAT = KC.LSFT(KC.LALT(KC.F))
COMMENT = KC.LCTL(KC.SLSH)
TERMINAL = KC.LCTL(KC.GRAVE)
SPLIT_EDITOR = KC.LCTL(KC.BSLS)
COMMAND_PALETTE = KC.LCTL(KC.LSFT(KC.P))
QUICK_OPEN = KC.LCTL(KC.P)

# Matrix order is row-major: row1 col1..3, row2 col1..3, row3 col1..3.
keyboard.keymap = [
    # Everyday
    [
        COPY, PASTE, CUT,
        UNDO, REDO, SELECT_ALL,
        SCREENSHOT, KC.MPLY, TO_GAMING,
    ],
    # Gaming
    [
        KC.N1, KC.N2, KC.N3,
        KC.Q, KC.E, KC.R,
        KC.LSFT, KC.SPC, TO_CODING,
    ],
    # Coding
    [
        RUN_NO_DEBUG, DEBUG, FORMAT,
        COMMENT, TERMINAL, SPLIT_EDITOR,
        COMMAND_PALETTE, QUICK_OPEN, TO_EVERYDAY,
    ],
]

# Encoder: left/right/click for each layer. Click is unused.
encoder.map = [
    ((KC.VOLD, KC.VOLU, KC.NO),),
    ((KC.VOLD, KC.VOLU, KC.NO),),
    ((KC.LCTL(KC.PGUP), KC.LCTL(KC.PGDN), KC.NO),),
]

# OLED is optional at runtime: keyboard still works if its library/display is absent.
try:
    import adafruit_ssd1306

    class StarfallOLED(Extension):
        def __init__(self):
            self.display = None
            self.last_layer = None
            try:
                i2c = busio.I2C(board.D5, board.D4)  # SCL, SDA
                self.display = adafruit_ssd1306.SSD1306_I2C(128, 32, i2c, addr=0x3C)
                self.display.fill(0)
                self.display.show()
            except Exception as exc:
                print('OLED disabled:', exc)
                self.display = None

        def during_bootup(self, keyboard):
            self._update(keyboard)

        def before_matrix_scan(self, keyboard):
            pass

        def on_runtime_enable(self, keyboard):
            pass

        def on_runtime_disable(self, keyboard):
            pass

        def after_matrix_scan(self, keyboard):
            self._update(keyboard)

        def before_hid_send(self, keyboard):
            pass

        def after_hid_send(self, keyboard):
            pass

        def on_powersave_enable(self, keyboard):
            pass

        def on_powersave_disable(self, keyboard):
            self._update(keyboard, force=True)

        def _update(self, keyboard, force=False):
            if self.display is None:
                return
            try:
                layer = keyboard.active_layers[0]
            except Exception:
                layer = 0
            if not force and layer == self.last_layer:
                return
            self.last_layer = layer
            names = ('EVERYDAY', 'GAMING', 'CODING')
            name = names[layer] if 0 <= layer < len(names) else 'STARFALL'
            self.display.fill(0)
            self.display.text('STARFALL', 0, 0, 1)
            self.display.text(name, 0, 13, 1)
            self.display.text('MODE  %d/3' % (layer + 1), 68, 22, 1)
            self.display.show()

    keyboard.extensions.append(StarfallOLED())
except ImportError as exc:
    print('OLED library missing:', exc)

if __name__ == '__main__':
    keyboard.go()

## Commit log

2026-09-12 Add Starfall bill of materials
    [BOM.csv]
2026-09-12 Add Gerber verification notes
2026-09-12 Finish README with case renders and BOM table
2026-09-16 Add generator for final Reactor Celestial case
2026-09-16 Generate final print-ready Celestial case artifacts
2026-09-16 Update final Reactor Celestial print-ready case [skip ci]
    [Bottom.STEP, Bottom.stl, Middle_Purple.STEP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]
2026-09-16 Document final Reactor Celestial case
2026-09-16 Finish Celestial case, recessed USB and OLED surround; shift L right
    [BOM.csv]
2026-09-16 Regenerate mechanically checked Reactor case and fit samples [skip ci]
    [Bottom.STEP, Bottom.stl, Insert_well_4p6_4p7_4p8.STEP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]
2026-09-18 Clarify PCB source and library path notes
2026-09-18 Make case workflow rebase before pushing generated files
2026-09-18 Remove unnecessary PRINTING.md
2026-09-18 Regenerate all case preview images
2026-09-18 Render current case in all preview images
2026-09-18 Speed up case preview rendering
2026-09-18 Update previews to latest corrected case
2026-09-19 Synchronize case downloads and show current PNG gallery [skip ci]
    [Starfall_assembled.STEP, Starfall_case_assembly.STEP]
2026-09-19 Add printable Starfall star knob, shaft samples and print pack
    [Dshaft_sample_6p1mm.STEP, Dshaft_sample_6p1mm.stl, Dshaft_sample_6p2mm.STEP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]
2026-09-21 Integrate printable knob and fix branch publishing [skip ci]
2026-09-21 Publish complete printer pack and refresh knob previews
2026-09-21 Refresh Starfall case images and assemblies with printable knob [skip ci]
    [Starfall_Fully_Assembled.STEP, Starfall_assembled.STEP]
